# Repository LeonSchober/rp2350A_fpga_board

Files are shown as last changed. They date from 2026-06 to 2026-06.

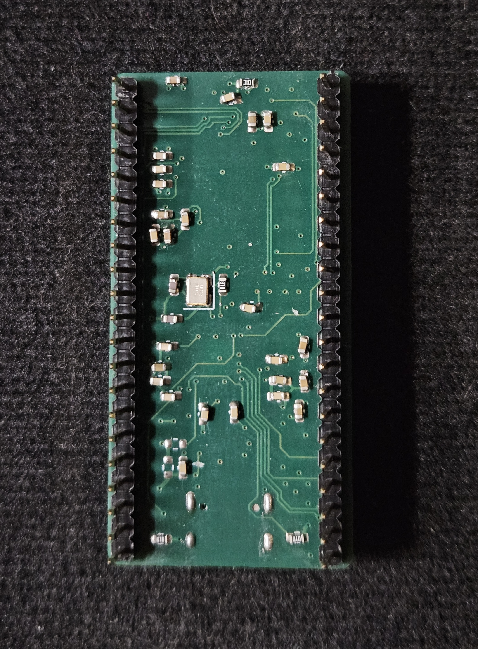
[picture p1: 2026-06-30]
hardware/3d/20260630_214854.jpg

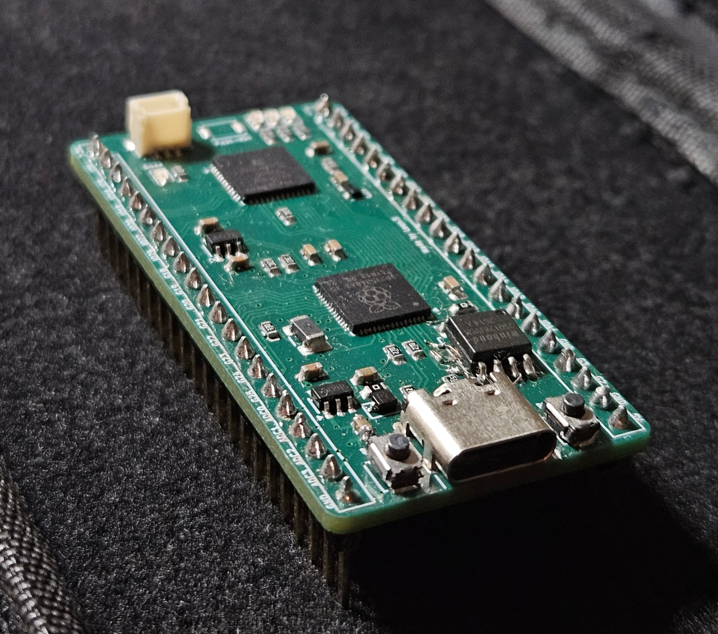
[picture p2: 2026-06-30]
hardware/3d/20260630_214738_1.jpg

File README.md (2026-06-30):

# rp2350A_fpga_board
rp2350A_fpga_board



RP2350 & iCE40 FPGA Development Board
This repository contains the hardware design files for a compact, high-performance development board combining the Raspberry Pi RP2350 MCU and the Lattice iCE40UP5K FPGA. This dual-chip architecture bridges the gap between flexible software execution and high-speed, parallel hardware acceleration, making it ideal for edge-computing, custom digital logic, and advanced interfacing projects.

Technical Specifications
Core Components
Microcontroller: Raspberry Pi RP2350A (ARM Cortex-M33 / Hazard3 RISC-V)

FPGA: Lattice iCE40 UltraPlus (iCE40UP5K-SG48ITR) – 5280 LUTs, 120 Kbit EBR, 1024 Kbit Single Port RAM

Storage: Winbond W25Q128JVS (128 Mbit / 16 MB QSPI Flash) shared/accessible for configuration

Power & Connectivity
Interface: USB Type-C for power, programming, and debugging

Power Management: Dual AP2112K LDO regulators providing stable 3.3V and 1.2V rails; onboard filtering networks for analog and PLL domains

User Interfacing: * Dedicated BOOT and RUN (Reset) buttons for the MCU

User-programmable button (Push-IO4) and status LEDs (Done, RGB)

High-density dual-row breadboard-compatible pin headers exposing GPIOs from both MCU and FPGA

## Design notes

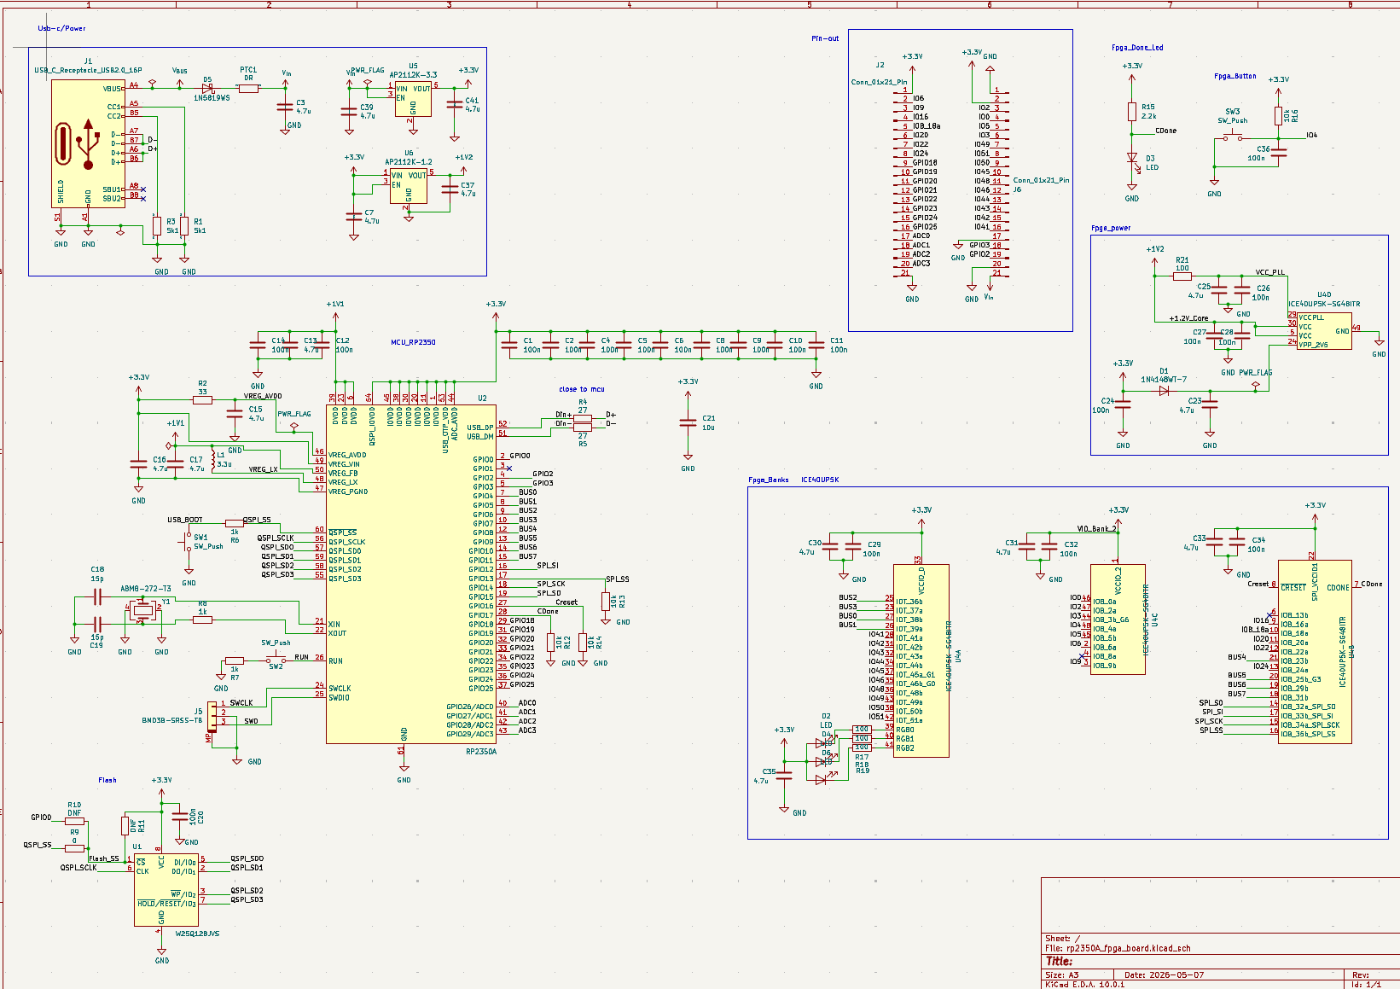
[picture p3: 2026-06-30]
hardware/schematic_rp2350a_fpga.png

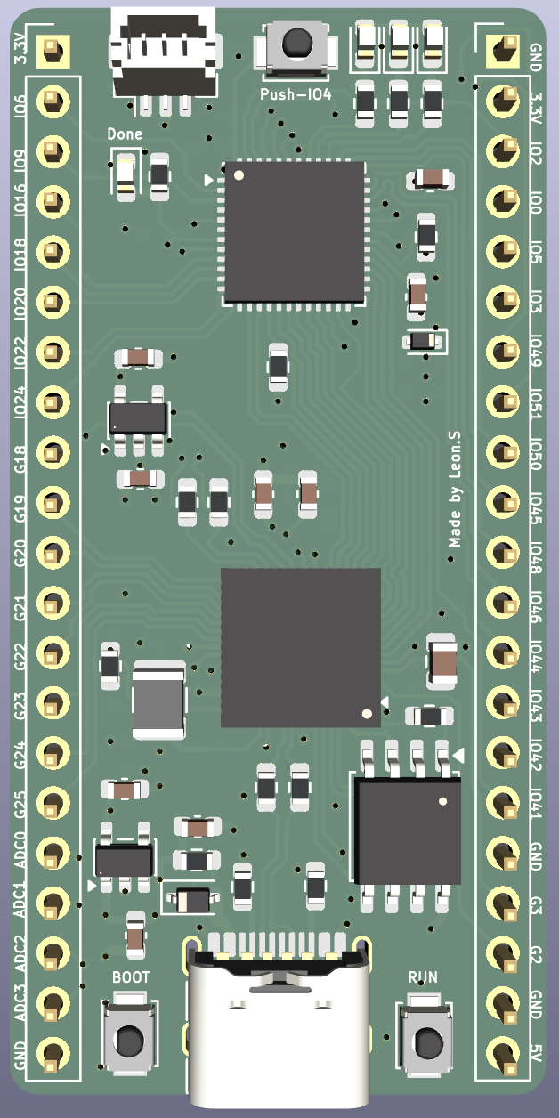
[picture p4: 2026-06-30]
hardware/3d/front.png

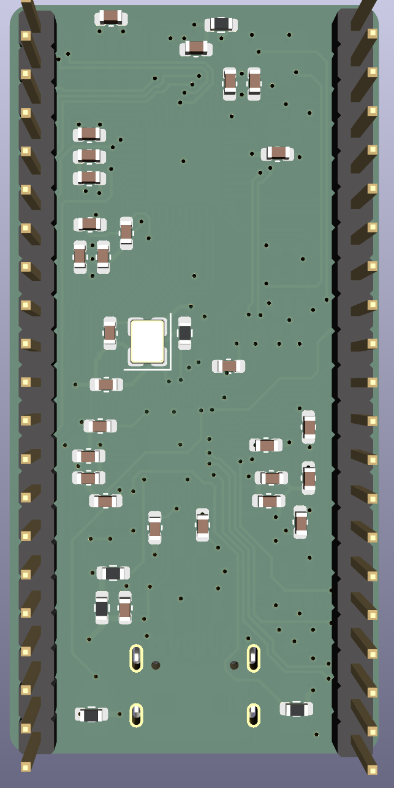
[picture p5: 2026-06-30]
hardware/3d/back.png

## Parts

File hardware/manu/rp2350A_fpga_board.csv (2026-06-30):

 Reference   Qty   Value   DNP   Exclude  from  BOM   Exclude  from  Board   Footprint   Datasheet   Beschreibung
 C1  C2  C4  C5  C6  C8  C9  C10  C11  C12  C14  C20  C24  C26  C27  C28  C29  C32  C34  C36   20   100n            Capacitor_SMD:C_0603_1608Metric      Unpolarized  capacitor
 C3  C7  C13  C15  C16  C17  C23  C25  C30  C31  C33  C35  C37  C39  C41   15   4.7u            Capacitor_SMD:C_0603_1608Metric   ~   CAP  CER  4.7UF  6.3V  X5R  0402,Unpolarized  capacitor
 C18  C19   2   15p            Capacitor_SMD:C_0603_1608Metric      Unpolarized  capacitor
 C21   1   10u            Capacitor_SMD:C_0805_2012Metric      Unpolarized  capacitor
 D1   1   1N4148WT-7            Diode_SMD:D_SOD-523   https://www.vishay.com/docs/85748/1n4148w.pdf   DIODE  GEN  PURP  80V  125MA  SOD523
 D2  D3  D4  D6   4   LED            LED_SMD:LED_0603_1608Metric      Light  emitting  diode
 D5   1   1N5819WS            Diode_SMD:D_SOD-323   ~   40V  600mV@1A  1A  SOD-323  Schottky  Barrier  Diodes  (SBD)  ROHS
 J1   1   USB_C_Receptacle_USB2.0_16P            Connector_USB:USB_C_Receptacle_G-Switch_GT-USB-7010ASV   https://www.usb.org/sites/default/files/documents/usb_type-c.zip   USB  2.0-only  16P  Type-C  Receptacle  connector
 J2  J6   2   Conn_01x21_Pin            Connector_PinHeader_2.54mm:PinHeader_1x21_P2.54mm_Vertical      Generic  connector,  single  row,  01x21,  script  generated
 J5   1   BM03B-SRSS-TB            Connector_JST:JST_SH_BM03B-SRSS-TB_1x03-1MP_P1.00mm_Vertical   ~   CONN  HEADER  SMD  3POS  1MM
 L1   1   3.3u            Inductor_SMD:L_1210_3225Metric      Inductor
 PTC1   1   0R            Resistor_SMD:R_0603_1608Metric   https://www.bourns.com/docs/Product-Datasheets/mffsmf.pdf   PTC  RESET  FUSE  6V  350MA  0603
 R1  R3   2   5k1            Resistor_SMD:R_0603_1608Metric   ~   Resistor
 R2   1   33            Resistor_SMD:R_0603_1608Metric      Resistor
 R4  R5   2   27            Resistor_SMD:R_0603_1608Metric      Resistor
 R6  R7  R8   3   1k            Resistor_SMD:R_0603_1608Metric      Resistor
 R9   1   0            Resistor_SMD:R_0603_1608Metric      Resistor
 R10  R11   2   DNF            Resistor_SMD:R_0603_1608Metric      Resistor
 R12  R13  R14  R16   4   10k            Resistor_SMD:R_0603_1608Metric      Resistor
 R15   1   2.2k            Resistor_SMD:R_0603_1608Metric      Resistor
 R17  R18  R19  R21   4   100            Resistor_SMD:R_0603_1608Metric      Resistor
 SW1  SW2  SW3   3   SW_Push            Button_Switch_SMD:SW_SPST_B3U-1000P      Push  button  switch,  generic,  two  pins
 U1   1   W25Q128JVS            Package_SO:SOIC-8_5.3x5.3mm_P1.27mm   https://www.winbond.com/resource-files/w25q128jv_dtr%20revc%2003272018%20plus.pdf   128Mbit  /  16MiB  Serial  Flash  Memory,  Standard/Dual/Quad  SPI,  2.7-3.6V,  SOIC-8
 U2   1   RP2350A            Package_DFN_QFN:QFN-60-1EP_7x7mm_P0.4mm_EP3.4x3.4mm   https://datasheets.raspberrypi.com/rp2350/rp2350-datasheet.pdf   A  microcontroller  by  Raspberry  Pi,  dual  CPU  architecture  (ARM  Cortex-M33  /  RISC-V  Hazard3),  150MHz,  no  flash,  520KB  SRAM,  12  PIO  state  machines,  VQFN-60
 U4   1   ICE40UP5K-SG48ITR            Package_DFN_QFN:QFN-48-1EP_7x7mm_P0.5mm_EP5.6x5.6mm   http://www.latticesemi.com/Products/FPGAandCPLD/iCE40Ultra   iCE40  UltraPlus  FPGA,  5280  LUTs,  1.2V,  48-pin  QFN
 U5   1   AP2112K-3.3            Package_TO_SOT_SMD:SOT-23-5   https://www.diodes.com/assets/Datasheets/AP2112.pdf   600mA  low  dropout  linear  regulator,  with  enable  pin,  3.8V-6V  input  voltage  range,  3.3V  fixed  positive  output,  SOT-23-5
 U6   1   AP2112K-1.2            Package_TO_SOT_SMD:SOT-23-5   https://www.diodes.com/assets/Datasheets/AP2112.pdf   600mA  low  dropout  linear  regulator,  with  enable  pin,  2.5V-6V  input  voltage  range,  1.2V  fixed  positive  output,  SOT-23-5
 Y1   1   ABM8-272-T3            Crystal:Crystal_SMD_3225-4Pin_3.2x2.5mm   ~   Crystal

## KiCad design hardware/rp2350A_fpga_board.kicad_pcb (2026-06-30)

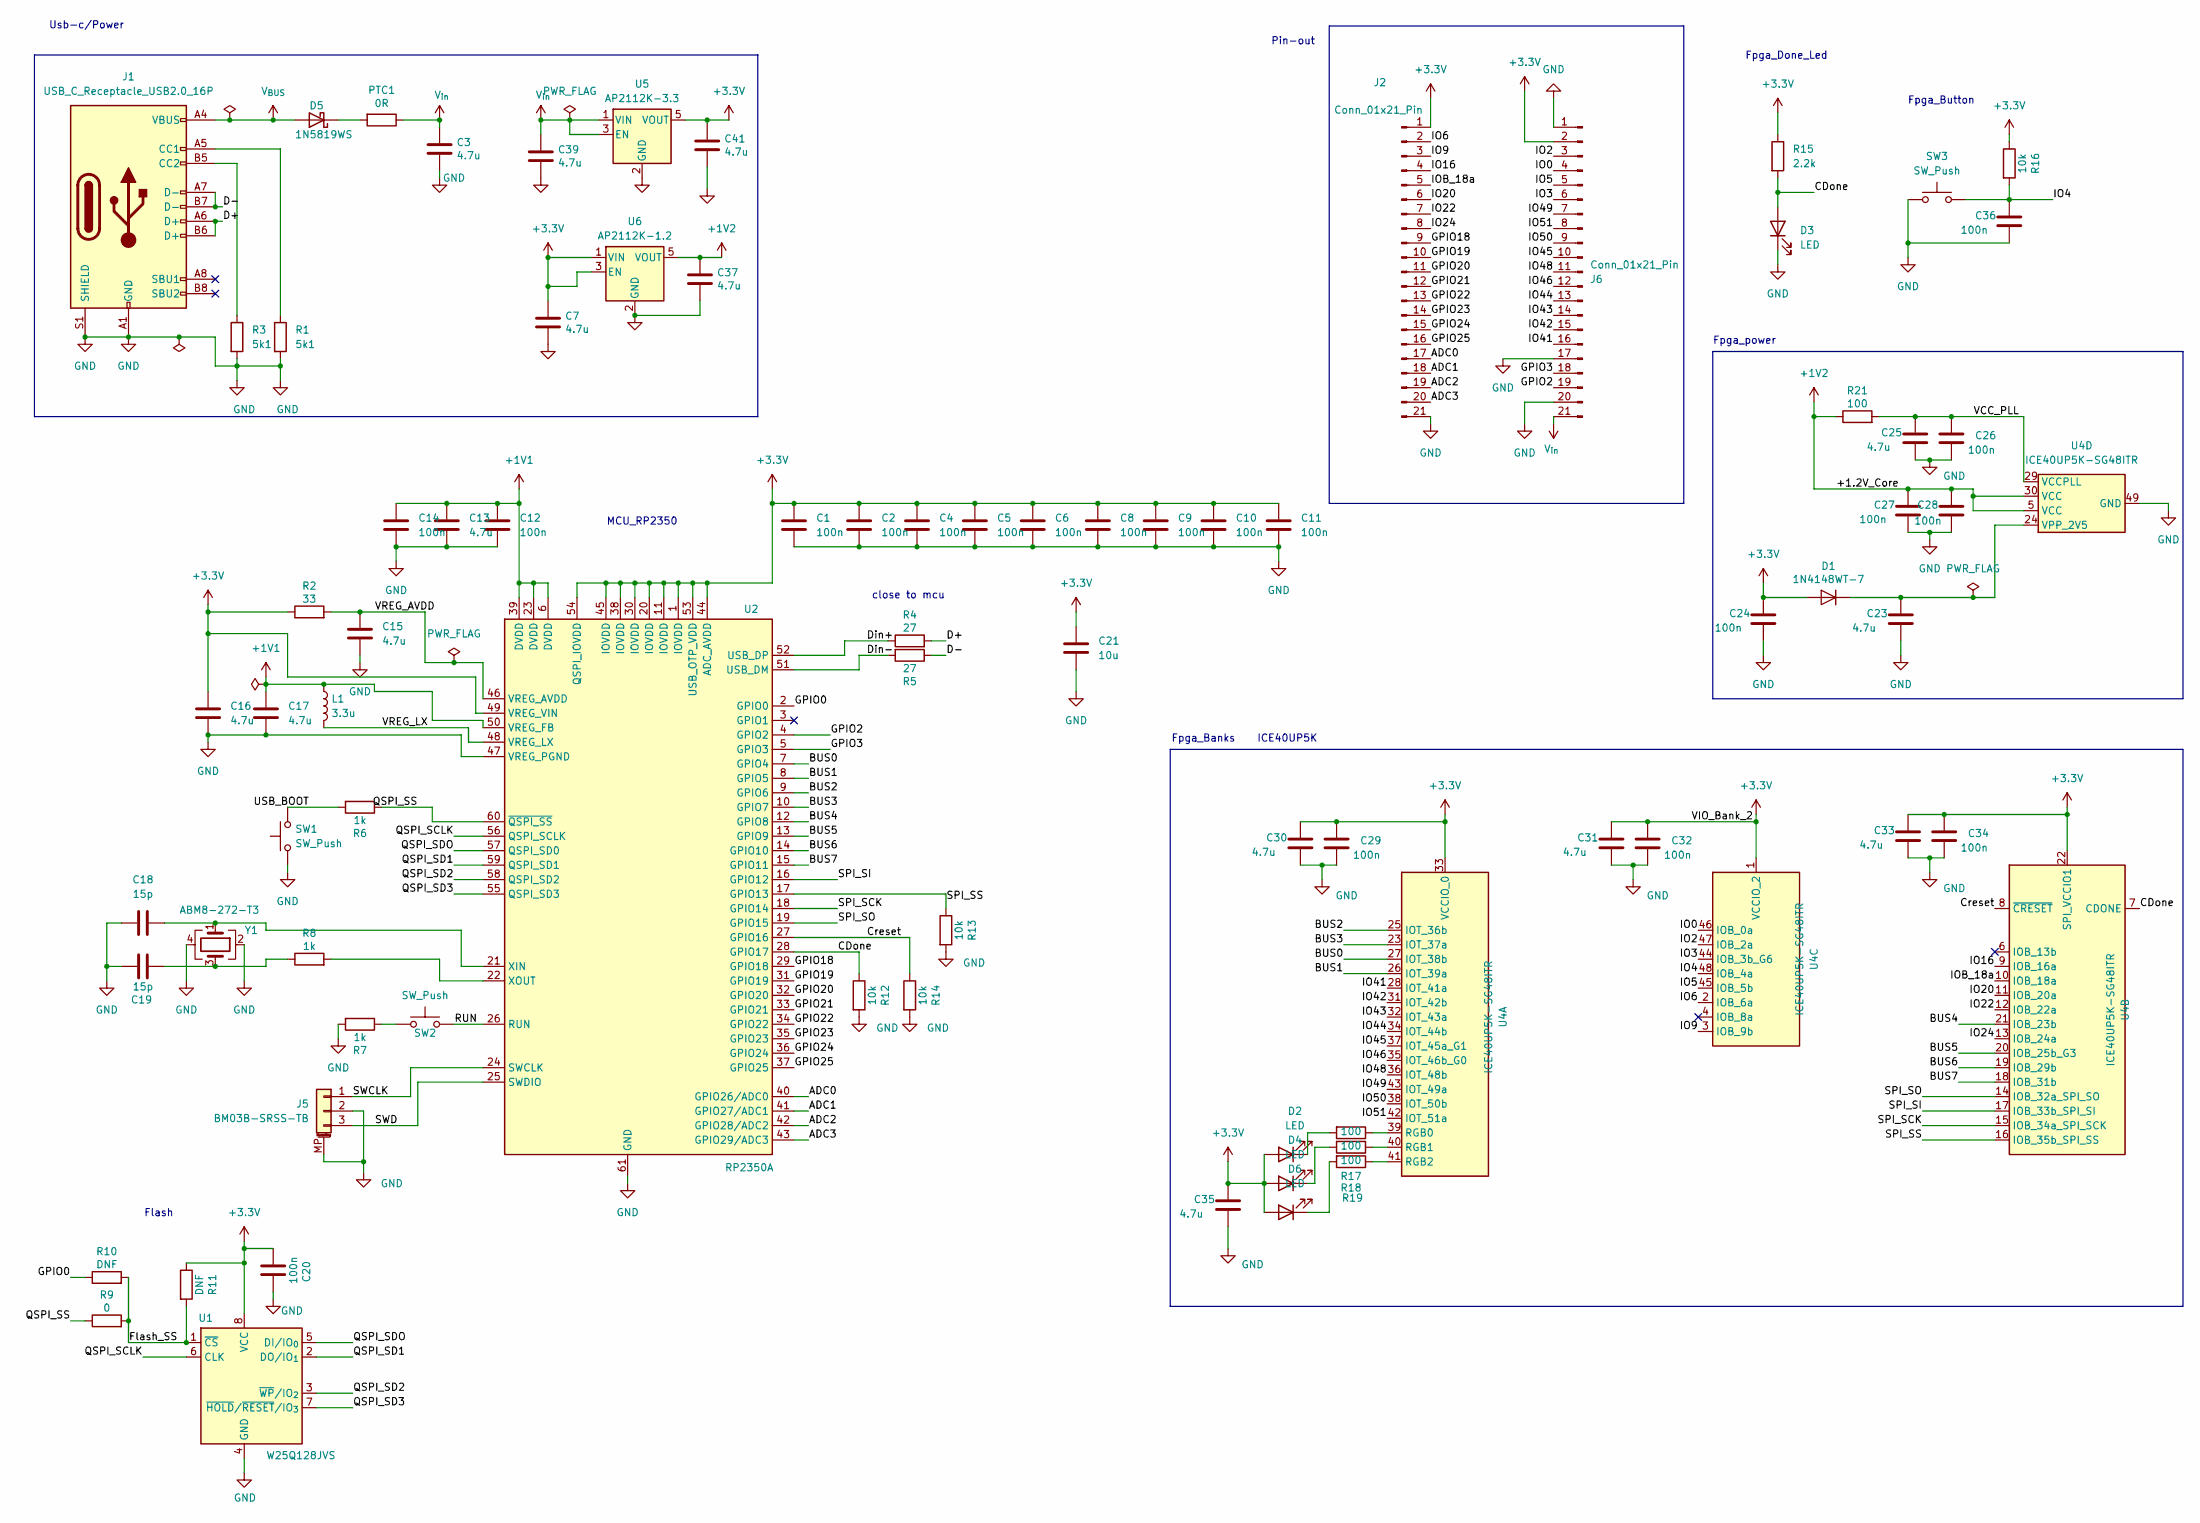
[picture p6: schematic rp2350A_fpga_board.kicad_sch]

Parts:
C1, C2, C4, C5, C6, C8, C9, C10, C11, C12, C14, C20, C24, C26, C27, C28, C29, C32, C34, C36: 100n; C_0603_1608Metric
C3, C7, C37, C39, C41: 4.7u; C_0603_1608Metric; MPN GRM155R60J475ME87D
C13, C15, C16, C17, C23, C25, C30, C31, C33, C35: 4.7u; C_0603_1608Metric
C18, C19: 15p; C_0603_1608Metric
C21: 10u; C_0805_2012Metric
D1: 1N4148WT-7; D_SOD-523; MPN 1N4148WT-7
D2, D3, D4, D6: LED; LED_0603_1608Metric
D5: 1N5819WS; D_SOD-323; MPN 1N5819WS
J1: USB_C_Receptacle_USB2.0_16P; USB_C_Receptacle_G-Switch_GT-USB-7010ASV
J2, J6: Conn_01x21_Pin; PinHeader_1x21_P2.54mm_Vertical
J5: BM03B-SRSS-TB; JST_SH_BM03B-SRSS-TB_1x03-1MP_P1.00mm_Vertical; MPN BM03B-SRSS-TB
L1: 3.3u; L_1210_3225Metric
PTC1: 0R; R_0603_1608Metric; MPN MF-FSMF035X-2
R1, R3: 5k1; R_0603_1608Metric
R2: 33; R_0603_1608Metric
R4, R5: 27; R_0603_1608Metric
R6, R7, R8: 1k; R_0603_1608Metric
R9: 0; R_0603_1608Metric
R10, R11: DNF; R_0603_1608Metric
R12, R13, R14, R16: 10k; R_0603_1608Metric
R15: 2.2k; R_0603_1608Metric
R17, R18, R19, R21: 100; R_0603_1608Metric
SW1, SW2, SW3: SW_Push; SW_SPST_B3U-1000P
U1: W25Q128JVS; SOIC-8_5.3x5.3mm_P1.27mm
U2: RP2350A; QFN-60-1EP_7x7mm_P0.4mm_EP3.4x3.4mm
U4: ICE40UP5K-SG48ITR; QFN-48-1EP_7x7mm_P0.5mm_EP5.6x5.6mm
U5: AP2112K-3.3; SOT-23-5
U6: AP2112K-1.2; SOT-23-5
Y1: ABM8-272-T3; Crystal_SMD_3225-4Pin_3.2x2.5mm; MPN ABM8-272-T3

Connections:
+1V1: C12.1, C13.1, C14.1, C17.1, L1.1, U2.6 (DVDD), U2.23 (DVDD), U2.39 (DVDD), U2.50 (VREG_FB)
+1V2: C27.1, C28.1, C37.1, R21.1, U4.5 (VCC), U4.30 (VCC), U6.5 (VOUT)
+3.3V: C1.1, C2.1, C4.1, C5.1, C6.1, C7.1, C8.1, C9.1, C10.1, C11.1, C16.1, C20.2, C21.1, C24.1, C29.1, C30.1, C31.1, C32.1, C33.1, C34.1, C35.1, C41.1, D1.2 (A), D2.2 (A), D4.2 (A), D6.2 (A), J2.1, J6.2, R2.1, R11.1, R15.1, R16.1, U1.8 (VCC), U2.1 (IOVDD), U2.11 (IOVDD), U2.20 (IOVDD), U2.30 (IOVDD), U2.38 (IOVDD), U2.44 (ADC_AVDD), U2.45 (IOVDD), U2.49 (VREG_VIN), U2.53 (USB_OTP_VDD), U2.54 (QSPI_IOVDD), U4.1 (VCCIO_2), U4.22 (SPI_VCCIO1), U4.33 (VCCIO_0), U5.5 (VOUT), U6.1 (VIN), U6.3 (EN)
/ADC0: J2.17, U2.40 (GPIO26/ADC0)
/ADC1: J2.18, U2.41 (GPIO27/ADC1)
/ADC2: J2.19, U2.42 (GPIO28/ADC2)
/ADC3: J2.20, U2.43 (GPIO29/ADC3)
/BUS0: U2.7 (GPIO4), U4.27 (IOT_38b)
/BUS1: U2.8 (GPIO5), U4.26 (IOT_39a)
/BUS2: U2.9 (GPIO6), U4.25 (IOT_36b)
/BUS3: U2.10 (GPIO7), U4.23 (IOT_37a)
/BUS4: U2.12 (GPIO8), U4.21 (IOB_23b)
/BUS5: U2.13 (GPIO9), U4.20 (IOB_25b_G3)
/BUS6: U2.14 (GPIO10), U4.19 (IOB_29b)
/BUS7: U2.15 (GPIO11), U4.18 (IOB_31b)
/CDone: D3.2 (A), R12.1, R15.2, U2.28 (GPIO17), U4.7 (CDONE)
/Creset: R14.1, U2.27 (GPIO16), U4.8 (~CRESET)
/D+: J1.A6 (D+), J1.B6 (D+), R4.2
/D-: J1.A7 (D-), J1.B7 (D-), R5.1
/Din+: R4.1, U2.52 (USB_DP)
/Din-: R5.2, U2.51 (USB_DM)
/Flash_SS: R9.2, R10.2, R11.2, U1.1 (~CS)
/GPIO0: R10.1, U2.2 (GPIO0)
/GPIO2: J6.19, U2.4 (GPIO2)
/GPIO3: J6.18, U2.5 (GPIO3)
/GPIO18: J2.9, U2.29 (GPIO18)
/GPIO19: J2.10, U2.31 (GPIO19)
/GPIO20: J2.11, U2.32 (GPIO20)
/GPIO21: J2.12, U2.33 (GPIO21)
/GPIO22: J2.13, U2.34 (GPIO22)
/GPIO23: J2.14, U2.35 (GPIO23)
/GPIO24: J2.15, U2.36 (GPIO24)
/GPIO25: J2.16, U2.37 (GPIO25)
/IO0: J6.4, U4.46 (IOB_0a)
/IO2: J6.3, U4.47 (IOB_2a)
/IO3: J6.6, U4.44 (IOB_3b_G6)
/IO4: C36.1, R16.2, SW3.2, U4.48 (IOB_4a)
/IO5: J6.5, U4.45 (IOB_5b)
/IO6: J2.2, U4.2 (IOB_6a)
/IO9: J2.3, U4.3 (IOB_9b)
/IO16: J2.4, U4.9 (IOB_16a)
/IO20: J2.6, U4.11 (IOB_20a)
/IO22: J2.7, U4.12 (IOB_22a)
/IO24: J2.8, U4.13 (IOB_24a)
/IO41: J6.16, U4.28 (IOT_41a)
/IO42: J6.15, U4.31 (IOT_42b)
/IO43: J6.14, U4.32 (IOT_43a)
/IO44: J6.13, U4.34 (IOT_44b)
/IO45: J6.10, U4.37 (IOT_45a_G1)
/IO46: J6.12, U4.35 (IOT_46b_G0)
/IO48: J6.11, U4.36 (IOT_48b)
/IO49: J6.7, U4.43 (IOT_49a)
/IO50: J6.9, U4.38 (IOT_50b)
/IO51: J6.8, U4.42 (IOT_51a)
/IOB_18a: J2.5, U4.10 (IOB_18a)
/QSPI_SCLK: U1.6 (CLK), U2.56 (QSPI_SCLK)
/QSPI_SD1: U1.2 (DO/IO_{1}), U2.59 (QSPI_SD1)
/QSPI_SD2: U1.3 (~WP/IO_{2}), U2.58 (QSPI_SD2)
/QSPI_SD3: U1.7 (~HOLD/~RESET/IO_{3}), U2.55 (QSPI_SD3)
/QSPI_SDO: U1.5 (DI/IO_{0}), U2.57 (QSPI_SD0)
/QSPI_SS: R6.1, R9.1, U2.60 (~QSPI_SS)
/RUN: SW2.2, U2.26 (RUN)
/SPI_SCK: U2.18 (GPIO14), U4.15 (IOB_34a_SPI_SCK)
/SPI_SI: U2.16 (GPIO12), U4.17 (IOB_33b_SPI_SI)
/SPI_SO: U2.19 (GPIO15), U4.14 (IOB_32a_SPI_SO)
/SPI_SS: R13.1, U2.17 (GPIO13), U4.16 (IOB_35b_SPI_SS)
/SWCLK: J5.1, U2.24 (SWCLK)
/SWD: J5.3, U2.25 (SWDIO)
/USB_BOOT: R6.2, SW1.2
/VCC_PLL: C25.1, C26.1, R21.2, U4.29 (VCCPLL)
/VREG_AVDD: C15.1, R2.2, U2.46 (VREG_AVDD)
/VREG_LX: L1.2, U2.48 (VREG_LX)
GND: C1.2, C2.2, C3.2, C4.2, C5.2, C6.2, C7.2, C8.2, C9.2, C10.2, C11.2, C12.2, C13.2, C14.2, C15.2, C16.2, C17.2, C18.1, C19.1, C20.1, C21.2, C23.2, C24.2, C25.2, C26.2, C27.2, C28.2, C29.2, C30.2, C31.2, C32.2, C33.2, C34.2, C35.2, C36.2, C37.2, C39.2, C41.2, D3.1 (K), J1.A1 (GND), J1.B1 (GND), J1.S1 (SHIELD), J2.21, J5.2, J5.MP (MountPin), J6.1, J6.17, J6.20, R1.2, R3.2, R7.2, R12.2, R13.2, R14.2, SW1.1, SW3.1, U1.4 (GND), U2.47 (VREG_PGND), U2.61 (GND), U4.49 (GND), U5.2 (GND), U6.2 (GND), Y1.2, Y1.4
unnamed: C19.2, R8.1, Y1.3
unnamed: C23.1, D1.1 (K), U4.24 (VPP_2V5)
unnamed: D2.1 (K), R17.2
unnamed: D4.1 (K), R18.2
unnamed: D5.1 (K), PTC1.2
unnamed: D6.1 (K), R19.2
unnamed: J1.A5 (CC1), R1.1
unnamed: J1.B5 (CC2), R3.1
unnamed: R7.1, SW2.1
unnamed: C18.2, U2.21 (XIN), Y1.1
unnamed: R8.2, U2.22 (XOUT)
unnamed: R17.1, U4.39 (RGB0)
unnamed: R18.1, U4.40 (RGB1)
unnamed: R19.1, U4.41 (RGB2)
V_{BUS}: D5.2 (A), J1.A4 (VBUS), J1.A9 (VBUS), J1.B4 (VBUS), J1.B9 (VBUS)
V_{in}: C3.1, C39.1, J6.21, PTC1.1, U5.1 (VIN), U5.3 (EN)

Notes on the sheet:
MCU_RP2350
ICE40UP5K
Usb-c/Power
Flash
Fpga_Done_Led
Fpga_power
Fpga_Banks
close to mcu
Pin-out
Fpga_Button

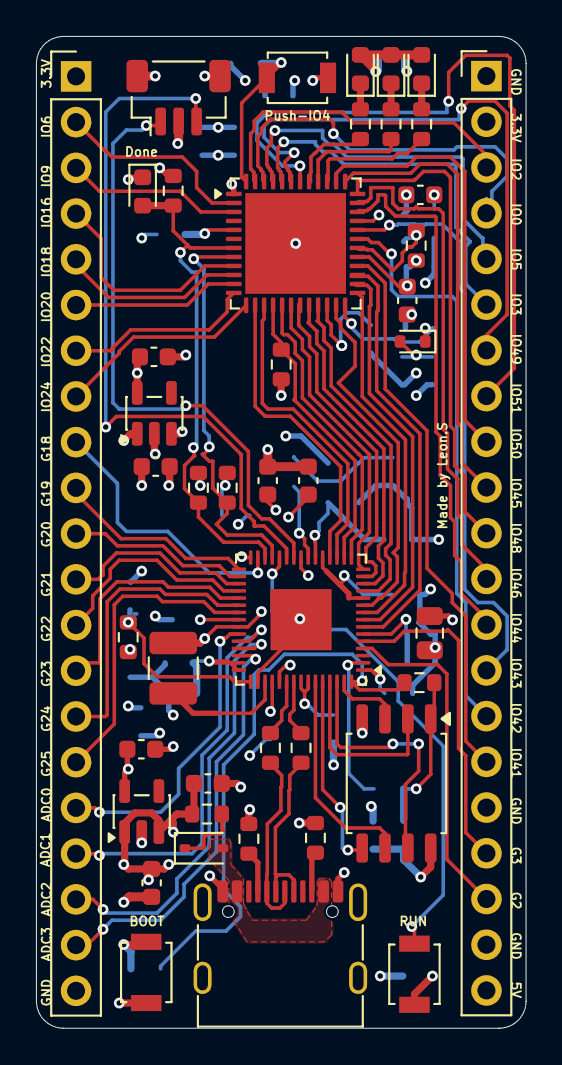
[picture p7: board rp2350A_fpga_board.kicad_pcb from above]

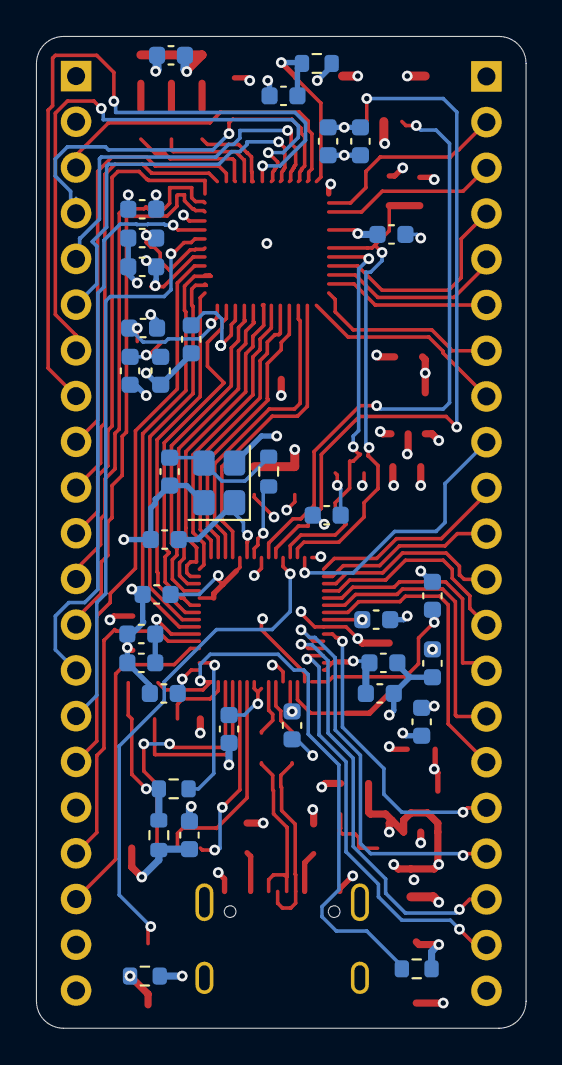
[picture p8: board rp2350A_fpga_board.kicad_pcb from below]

Board: 4 copper layers, 27.2 x 55.1 mm, 79 parts (35 on the bottom side), 89 nets.

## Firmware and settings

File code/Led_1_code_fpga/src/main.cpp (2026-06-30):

// main.cpp – RP2350A programmiert ICE40UP5K per Slave-SPI

#include <Arduino.h>
#include <SPI.h>

#include "fpga_bitstream.h"
const uint8_t* bitfile     = (const uint8_t*)firmware_bin;
const uint32_t  bitfile_len = 12345;
// ── GPIO Pins (Exakt abgestimmt auf RP2350 Hardware-SPI1) ─────────────────
constexpr uint8_t PIN_FPGA_MISO   = 12;  // GPIO12 ← SPI1 RX (FPGA SO)
constexpr uint8_t PIN_FPGA_CS     = 13;  // GPIO13 → SPI1 CSn (FPGA SS)
constexpr uint8_t PIN_FPGA_SCK    = 14;  // GPIO14 → SPI1 SCK (FPGA CLK)
constexpr uint8_t PIN_FPGA_MOSI   = 15;  // GPIO15 → SPI1 TX (FPGA SI)
constexpr uint8_t PIN_FPGA_CRESET = 16;  // GPIO16 → Creset (Hardware-Reset)
constexpr uint8_t PIN_FPGA_CDONE  = 17;  // GPIO17 ← CDone (Status-Pin)

// ── SPI1 Pins setzen ──────────────────────────────────────────────────────
void spi_init_pins() {
    SPI1.setSCK(PIN_FPGA_SCK);
    SPI1.setTX(PIN_FPGA_MOSI);
    SPI1.setRX(PIN_FPGA_MISO);
    SPI1.setCS(PIN_FPGA_CS);
}

// ── Hilfsfunktionen ───────────────────────────────────────────────────────
void spi_send(const uint8_t* data, size_t len) {
    for (size_t i = 0; i < len; i++) {
        SPI1.transfer(data[i]);
    }
}

// ── Debug Info ────────────────────────────────────────────────────────────
void debug_info() {
    Serial.println("\n[DEBUG] System Info:");
    Serial.printf("  Freier Heap    : %d Bytes\n", rp2040.getFreeHeap());
    Serial.printf("  Bitfile Groesse: %lu Bytes\n", bitfile_len);
    Serial.printf("  Erste 4 Bytes  : 0x%02X 0x%02X 0x%02X 0x%02X\n",
                  bitfile[0], bitfile[1], bitfile[2], bitfile[3]);

    // Korrekter iCE40 Header-Check (iCE40 Bitstreams starten oft mit 0xFF)
    if (bitfile[0] == 0xFF) {
        Serial.println("  Bitfile Header: OK (Startet mit 0xFF Sync)");
    } else {
        Serial.println("  WARNUNG: Bitfile Header ungewöhnlich! Prüfe das raw-Format.");
    }

    Serial.printf("  CRESET : %s\n", digitalRead(PIN_FPGA_CRESET) ? "HIGH" : "LOW");
    Serial.printf("  CDONE  : %s\n", digitalRead(PIN_FPGA_CDONE)  ? "HIGH" : "LOW");
    Serial.println();
}

// ── FPGA Konfiguration ────────────────────────────────────────────────────
bool fpga_configure() {
    Serial.println("[FPGA] Starte Konfiguration...");

    // Schritt 1: Beide Pins definiert hochsetzen
    digitalWrite(PIN_FPGA_CS,     HIGH);
    digitalWrite(PIN_FPGA_CRESET, HIGH);
    delay(10);

    // Schritt 2: CS LOW, dann CRESET LOW (Zwingt iCE40 in den Slave-SPI Modus)
    digitalWrite(PIN_FPGA_CS,     LOW);
    delay(1);
    digitalWrite(PIN_FPGA_CRESET, LOW);
    delay(2);  // min. 200ns laut Datenblatt

    // Schritt 3: CRESET wieder HIGH (CS MUSS dabei zwingend LOW bleiben!)
    digitalWrite(PIN_FPGA_CRESET, HIGH);
    delay(5);  // iCE40 braucht bis zu 1.2ms zum Löschen des internen RAMs

    // Schritt 4: CDONE sollte jetzt LOW sein (Bereit für Daten)
    Serial.printf("  CDONE vor Konfig: %s (erwartet: LOW)\n",
                  digitalRead(PIN_FPGA_CDONE) ? "HIGH" : "LOW");

    // Schritt 5: 8 Dummy-Clocks mit CS HIGH
    digitalWrite(PIN_FPGA_CS, HIGH);
    delayMicroseconds(10);
    SPI1.transfer(0x00);  // 8 Clocks erzeugen
    delayMicroseconds(10);

    // Schritt 6: CS wieder LOW für die eigentliche Übertragung
    digitalWrite(PIN_FPGA_CS, LOW);
    delayMicroseconds(10);

    Serial.print("[FPGA] Sende Bitfile... ");
    Serial.flush();
    uint32_t t = millis();
    
    // Bitstream via SPI jagen
    spi_send(bitfile, bitfile_len);
    
    Serial.printf("fertig in %lums\n", millis() - t);

    // Schritt 7: CS wieder HIGH setzen
    digitalWrite(PIN_FPGA_CS, HIGH);

    // Schritt 8: Mindestens 49 zusätzliche Takte (Wake-up Clocks)
    // Damit taktet sich das FPGA aus dem Konfigurationsmodus in den User-Modus
    for (int i = 0; i < 7; i++) {
        SPI1.transfer(0x00);  // 7 * 8 = 56 Clocks
    }

    // Schritt 9: Kurze Pause und Erfolgskontrolle
    delay(100);
    bool success = (digitalRead(PIN_FPGA_CDONE) == HIGH);
    
    Serial.printf("  CDONE nach Konfig: %s\n", success ? "HIGH (ERFOLG!)" : "LOW (FEHLER)");
    Serial.println(success ? "[FPGA] Bootvorgang abgeschlossen!" : "[FPGA] Konfiguration fehlgeschlagen!");
    
    return success;
}

// ── Setup ─────────────────────────────────────────────────────────────────
void setup() {
    Serial.begin(115200);
    
    // Wartezeit beim Booten, damit du Zeit hast, den Serial Monitor zu öffnen
    delay(3000); 
    Serial.println("\n=== RP2350A TO iCE40 BOOTLOADER ===");
    Serial.flush();

    // GPIO Richtungen festlegen
    pinMode(PIN_FPGA_CS,     OUTPUT);
    pinMode(PIN_FPGA_CRESET, OUTPUT);
    pinMode(PIN_FPGA_CDONE,  INPUT);
    pinMode(PIN_FPGA_MISO, INPUT_PULLUP);

    // Grundzustand herstellen
    digitalWrite(PIN_FPGA_CS,     HIGH);
    digitalWrite(PIN_FPGA_CRESET, HIGH);

    // Zeige Debug-Werte im Terminal
    debug_info();

    // SPI1 initialisieren
    spi_init_pins();
    SPI1.begin();
    
    // Auf 5 MHz reduziert (5000000UL) für saubere Signale ohne Reflexionen
    SPI1.beginTransaction(SPISettings(5000000UL, MSBFIRST, SPI_MODE0));

    // FPGA programmieren
    if (!fpga_configure()) {
        SPI1.endTransaction();
        SPI1.end();
        Serial.println("[ERROR] Programmierung abgebrochen.");
        while (true) {
            Serial.println("[ERROR] Halted – Bitte Verkabelung und Pull-Ups prüfen.");
            delay(5000);
        }
    }

    // SPI nach erfolgreicher Programmierung freigeben
    SPI1.endTransaction();
    SPI1.end();

    Serial.println("[INFO] FPGA ist aktiv und läuft im User-Mode.");
}

// ── Loop ──────────────────────────────────────────────────────────────────
void loop() {
    static uint32_t last = 0;
    if (millis() - last >= 5000) {
        last = millis();
        bool cdone_status = digitalRead(PIN_FPGA_CDONE);
        Serial.printf("[STATUS] CDONE=%s  Uptime=%lus\n",
                      cdone_status ? "OK (HIGH)" : "FAIL (LOW)",
                      millis() / 1000UL);
    }
}
